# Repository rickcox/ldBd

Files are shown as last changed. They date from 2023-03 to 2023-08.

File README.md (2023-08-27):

# ldBd
Simple Load Board for Power Supply Testing

This is a very simple PCB design to act as a power supply load board.  
Yes, there are fancy load boards available out there with digital readouts, fans, etc.
This goes opposite that - it is ***trivially simple***.
This is a simple 2 sided PCB 100mm X 100mm with 50 and 25 watt power resistors that can
be connected various ways using banana plug jumpers.
(See notes on the back of the PCB for some options)

It's a bit of a squeeze getting everything to fit, but staying at 100mmX100mm keeps board manufacturing inexpensive.
You can have bare PCB's fabricated for you very inexpensively.
(For example I paid $2.00 + shipping for 5 bare boards from https://jlcpcb.com)

The files needed for PCB manufacturing are in the 'gerbers/'
directory.  The design was done in KiCad version 7, and the files with extensions "kicad_*" can be used to
modify it further, if you wish.

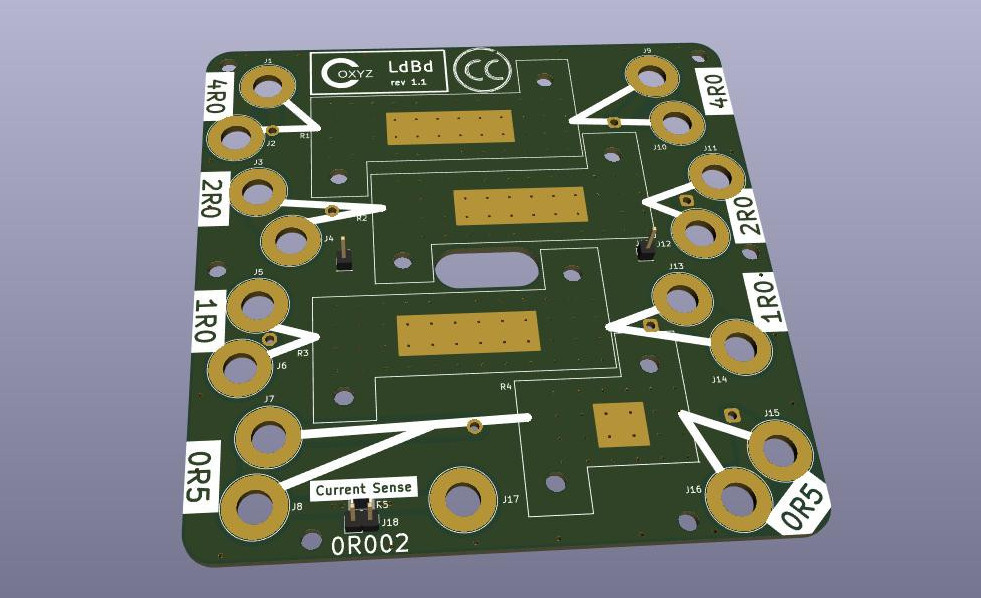
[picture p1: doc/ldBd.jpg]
A View of the Raw Board


The power resistors are connected to the board mounting holes via short soldered jumpers and M3 bolts/nuts.
The whole top and bottom surfaces are mostly big copper pours, so resistor heat is spread across the entire board.

I haven't generated an official BOM, but the parts list is fairly simple:

- R1 is a 4 ohm, 50 watt power resistor
- R2 is a 2 ohm, 50 watt power resistor
- R3 is a 1 ohm, 50 watt power resistor
- R4 is a 0.5 ohm, 25 watt power resistor
- J1-17 (17 items) are banana jacks. I used black on one side and red on the other, but .. whatever you want.
- If you want the current sense option, J18 is a 1X2 0.1" pin header, and R5 is a 0.002 ohm 1206 sized surface mount resistor. Both are easy to hand solder.
- You will also need some M3 bolts&nuts - or similar - to hold the resistors down.
- and of course you need to make or buy banana plug jumpers.

Talking about parts; I am US based. The load resistors are available at reasonable prices from most any electronics
distributor - Digikey, Mouser, Newark, etc.  However, the only place I could find banana jacks
and plugs at a reasonable price (I don't consider > $1 each to be reasonable) was from China.
The jacks&plugs I used were from AliExpress - and YES as you can see if you look closely at the next picture - 
*the same supplier gave me 2 different styles*!

I 3d printed a simple base for the board.  The stl file for that is in the 'case/' directory. Use M3 bolts to fasten the board down.
Since the board CAN get quite warm, PETG or an alternate material with a higher glass transition temperature than PLA is recommended.

And here's ***my*** finished product!

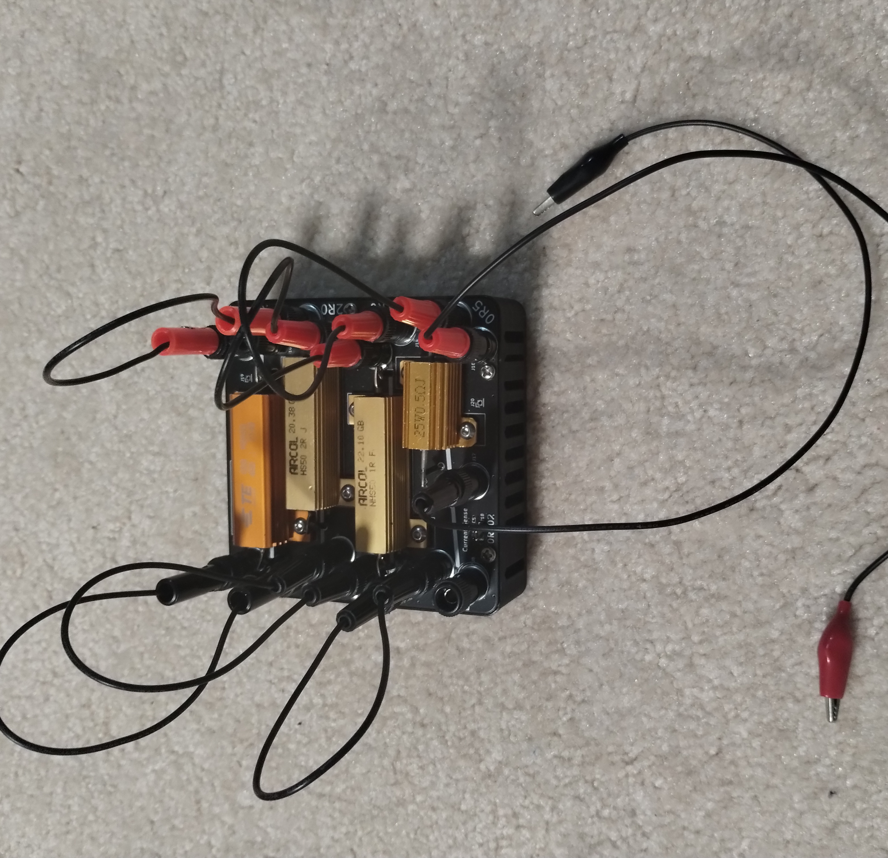
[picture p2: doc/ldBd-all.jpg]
Finished ldBd


Usage is simple - you need to know `e = i * r` and how to calculate effective parallel and series resistances.
(Again, see the notes on the back of the board for some ideas)
back 

Also - ***Use common sense***. Do not exceed the resistor ratings! I have found dissipating even 20 watts continuously
for 5-10 minutes on this board can make it get very warm. Use a fan if needed to increase heat transfer.

This work is licensed under the Creative Commons Attribution 4.0 International License. To view a copy of the license, visit https://creativecommons.org/licenses/by/4.0/

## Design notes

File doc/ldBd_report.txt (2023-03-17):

PCB statistics report
=====================
- Date: Thu 16 Mar 2023 07:50:49 PM PDT
- Project: ldBd
- Board name: ldBd

Board
-----
- Width: 100.0000 mm
- Height: 100.0000 mm
- Area: 9978.3364 mm²

Pads
----
- Through hole: 29
- SMD: 2
- Connector: 0
- NPTH: 14

Vias
----
- Through vias: 197
- Blind/buried: 0
- Micro vias: 0

Components
----------

| | Front Side | Back Side | Total |
|---|---|---|---|
|THT: | 25 | 0 | 25 |
|SMD: | 1 | 0 | 1 |
|Unspecified:  | 7 | 0 | 7 |
|Total: | 33 | 0 | 33 |

Drill holes
-----------

| Count | Shape | X Size | Y Size | Plated | Via/Pad | Start Layer | Stop Layer |
|---|---|---|---|---|---|---|---|
| 168 | Round | 0.5000 mm | 0.5000 mm | PTH | Via | F.Cu | B.Cu |
| 29 | Round | 0.7000 mm | 0.7000 mm | PTH | Via | F.Cu | B.Cu |
| 17 | Round | 5.5000 mm | 5.5000 mm | PTH | Pad | F.Cu | B.Cu |
| 8 | Round | 3.3000 mm | 3.3000 mm | NPTH | Pad | F.Cu | B.Cu |
| 8 | Round | 1.5000 mm | 1.5000 mm | PTH | Pad | F.Cu | B.Cu |
| 6 | Round | 3.2000 mm | 3.2000 mm | NPTH | Pad | F.Cu | B.Cu |
| 4 | Round | 1.0000 mm | 1.0000 mm | PTH | Pad | F.Cu | B.Cu |

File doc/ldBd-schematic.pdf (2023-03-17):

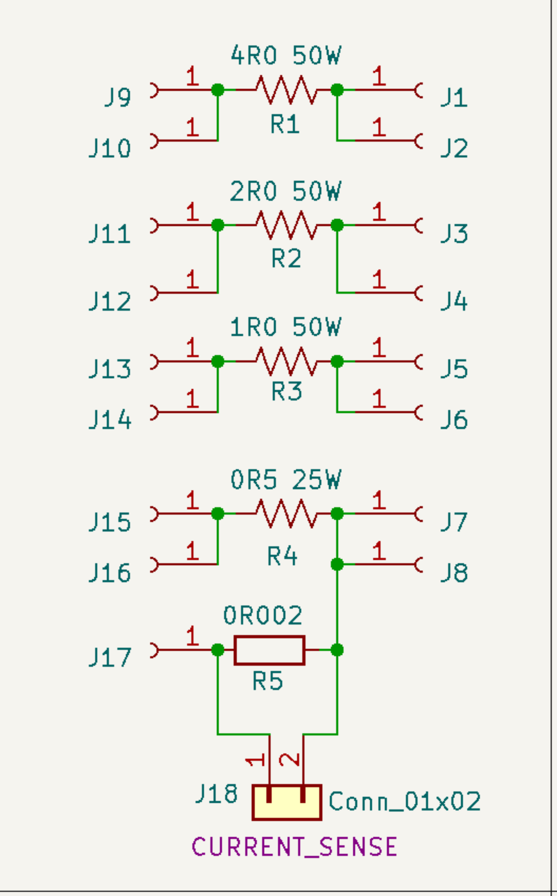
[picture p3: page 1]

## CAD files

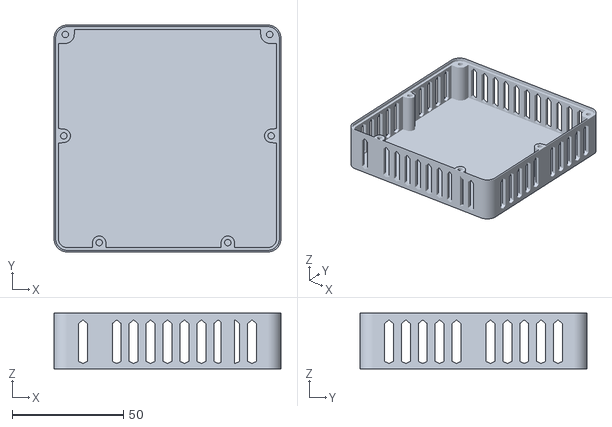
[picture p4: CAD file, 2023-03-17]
case/ldBd-base.stl
102.0 x 102.0 x 25.0

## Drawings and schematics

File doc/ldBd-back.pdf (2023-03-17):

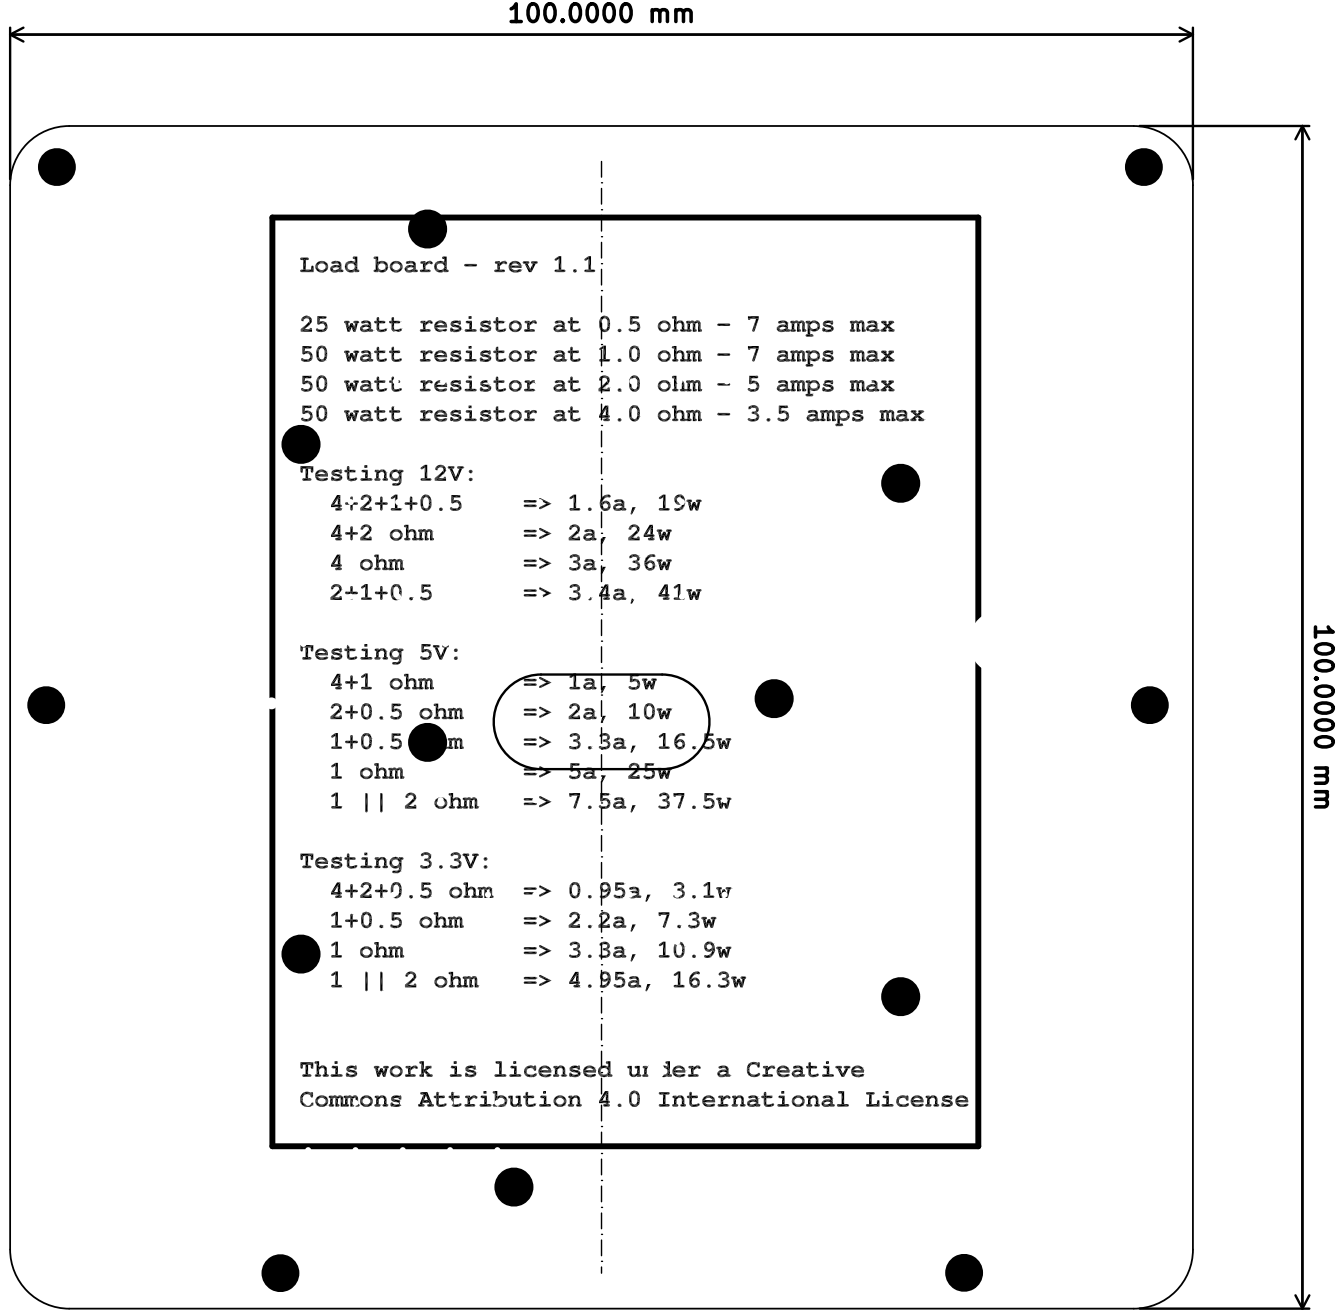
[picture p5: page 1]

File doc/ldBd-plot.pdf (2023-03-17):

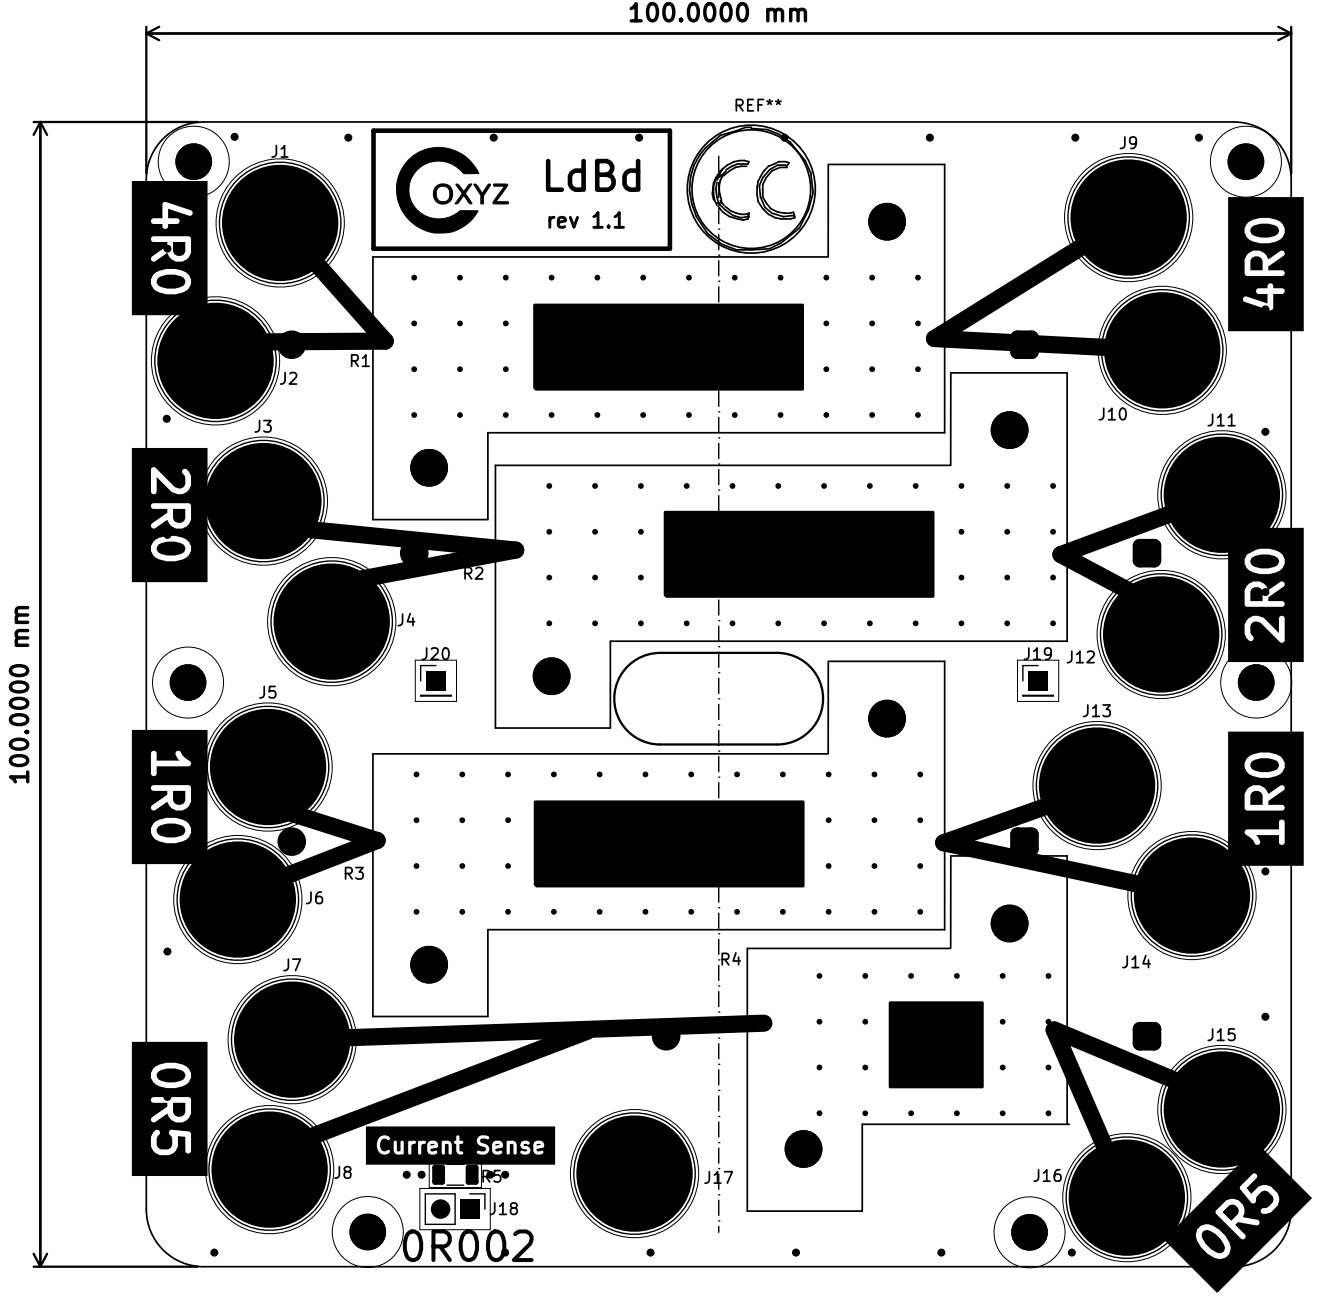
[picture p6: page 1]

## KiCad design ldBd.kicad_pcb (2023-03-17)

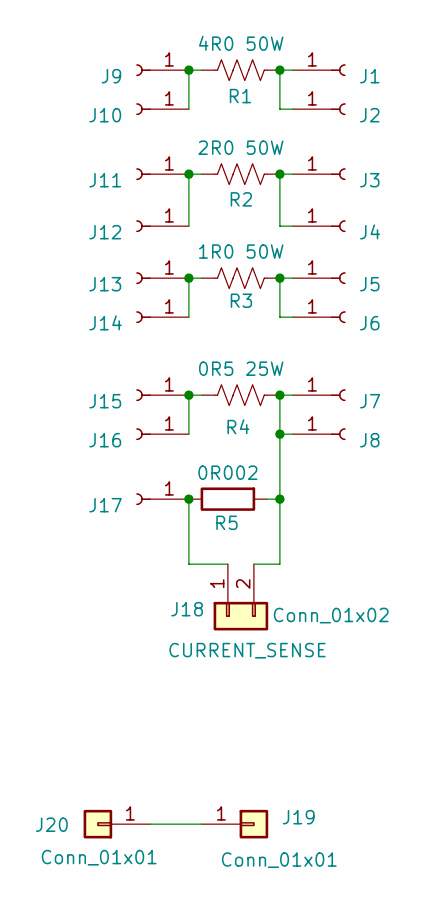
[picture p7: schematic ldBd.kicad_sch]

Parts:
J1, J2, J3, J4, J5, J6, J7, J8, J9, J10, J11, J12, J13, J14, J15, J16, J17: Conn_01x01_Female; Banana_Jack_1Pin
J18: Conn_01x02; PinHeader_1x02_P2.54mm_Vertical
J19, J20: Conn_01x01; PinHeader_1x01_P2.54mm_Vertical
R1: 4R0 50W; R_POWER_50W
R2: 2R0 50W; R_POWER_50W
R3: 1R0 50W; R_POWER_50W
R4: 0R5 25W; R_POWER_25W
R5: 0R002; R_1206_3216Metric

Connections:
unnamed: J1.1, J2.1, R1.2
unnamed: J3.1, J4.1, R2.2
unnamed: J5.1, J6.1, R3.2
unnamed: J9.1, J10.1, R1.1
unnamed: J11.1, J12.1, R2.1
unnamed: J13.1, J14.1, R3.1
unnamed: J15.1, J16.1, R4.1
unnamed: J17.1, J18.1, R5.1
unnamed: J7.1, J8.1, J18.2, R4.2, R5.2
unnamed: J19.1, J20.1

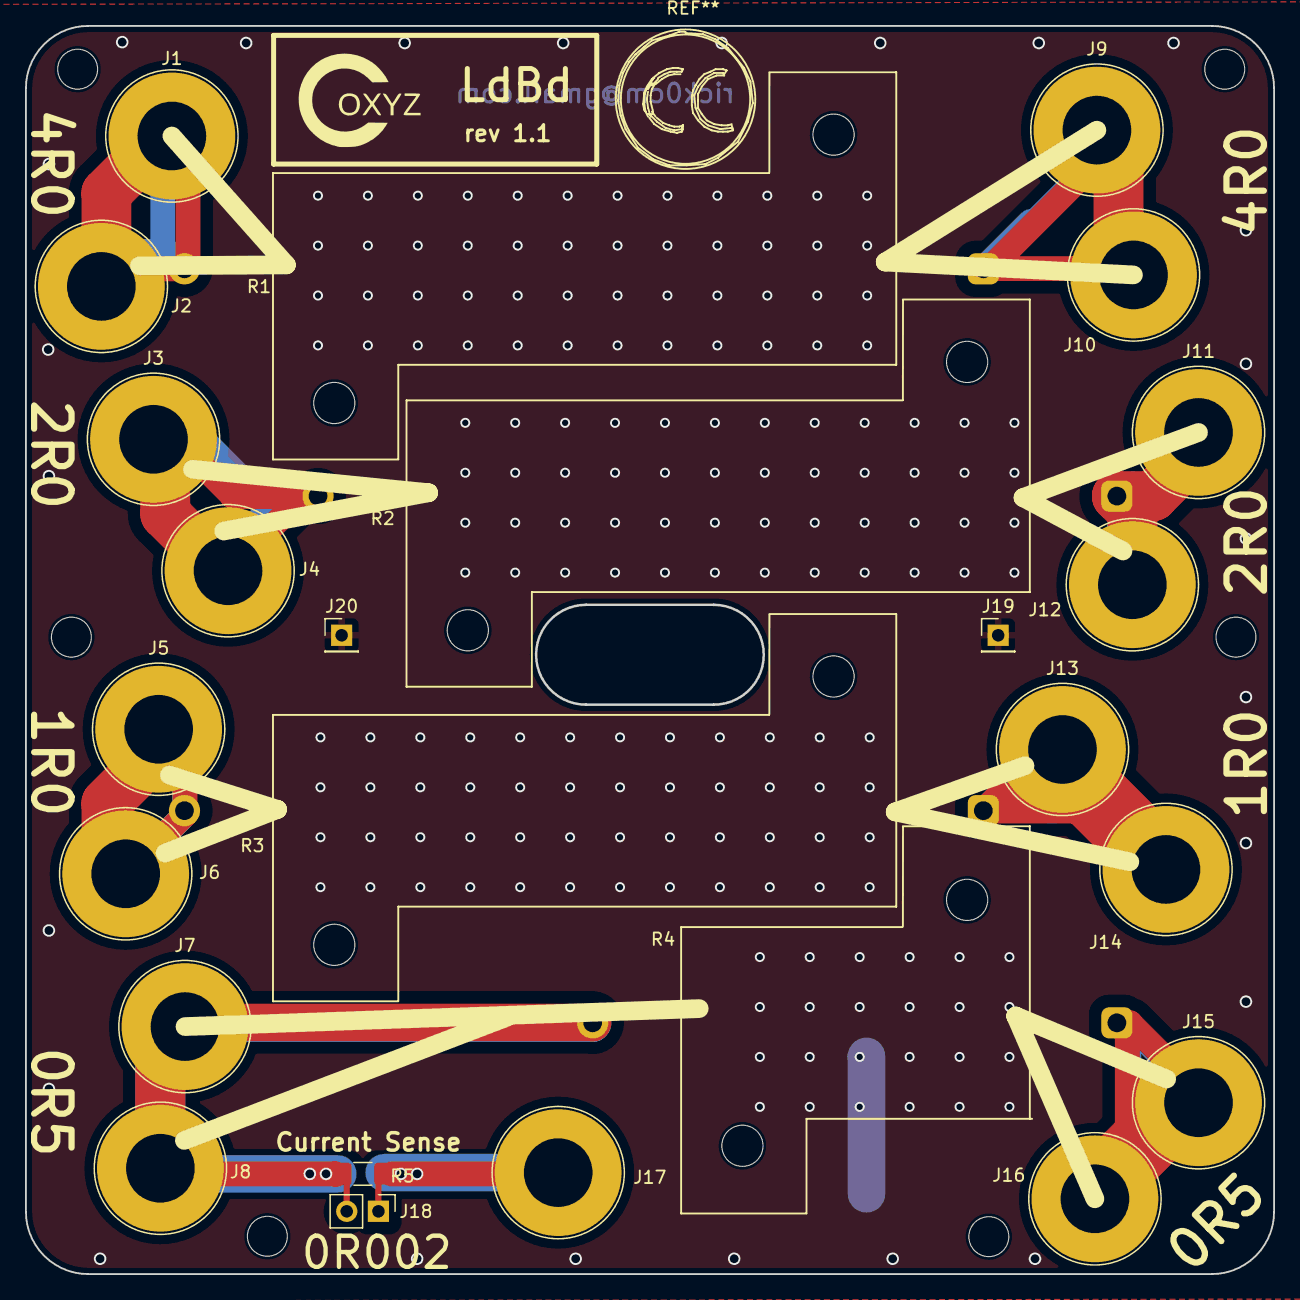
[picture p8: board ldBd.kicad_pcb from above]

Board: 2 copper layers, 100.0 x 100.0 mm, 25 parts (0 on the bottom side), 10 nets.

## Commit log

2023-03-17 initial push
    [ldBd-base.stl, ldBd.kicad_pcb, ldBd.kicad_sch]
2023-03-17 Add schematic
2023-03-30 Add pointer to pcb back

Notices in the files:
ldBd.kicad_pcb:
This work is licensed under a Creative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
